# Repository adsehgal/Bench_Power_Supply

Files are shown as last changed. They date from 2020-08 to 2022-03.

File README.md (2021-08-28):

<!-- ![](https://github.com/adsehgal/adsehgal/blob/master/LOGO.png) -->

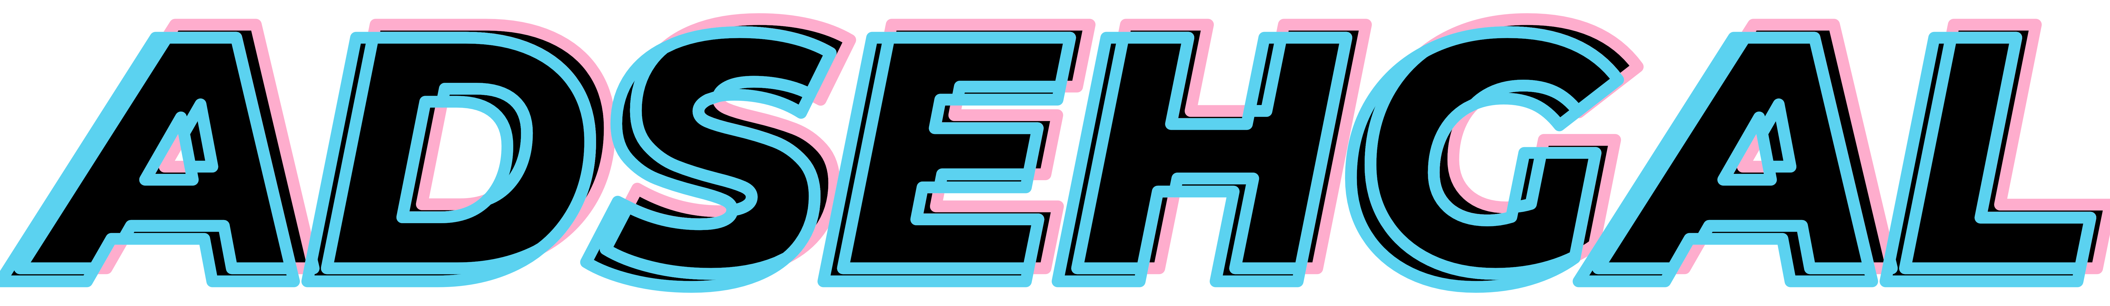
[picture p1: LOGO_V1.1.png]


# _Bench Power Supply PCB_

This repo contains project files for a bench top power supply I designed for my home lab.

## _Requirements:_

- **Small** for crammed work spaces
- **Adjustable** and designed to **store values** on each power cycle
- **2 layer** board - V2.0 bumped to 4 layer
- **Digitally controlled** - no mechanical parts
- Clear **annunciators**
- Uses an external AC-DC converter
- At least a **2A max** load
- Cover most logic levels
- _Possibly have preset buttons_

## Built With:

#### V1.0:

- [KiCad](https://kicad-pcb.org/) - Schematic capture and layout V1.0
- [VS Code | PlatformIO](https://code.visualstudio.com/) - Used to develop firmware V1.0
- [Fusion 360](https://www.autodesk.com/education/edu-software/overview) - Used to design 3-D models for packages

#### V2.0:

- [Altium Designer](https://www.altium.com/) - Schematic capture and layout V2.0
- [STM32CubeIDE](https://www.st.com/en/development-tools/stm32cubeide.html) - Used to develop firmware V2.0

## Notes:

- The PCB uses a 5/5mil DRC constraint
- The top of the PCB acts as the product face plate

## Firmware Changes:

| Change Type | V 1.0 | V2.0 |
| --- | --- | --- |
| MCU Architecture | 8-bit AVR | 32-bit ARM |
| User Input Handling  | Polling | Interrupts |
| Analog Readings | Polling | DMA |
| Serial Communication | None | Added |
| Operating System | None | FREERTOS |
| | | |

## Hardware Changes:

| Change Type | V 1.0 | V2.0 |
| --- | --- | --- |
| MCU Selection | ATMega 328p | STM32F401RB |
| Digi Pot | MCP4023 - Up/Down | MCP4018 - I2C |
| Inductor Seletion | 4.7µH - 7A | 4.7µH - 4A |
| PCB Stackup | 2-layer | 4-layer |
| User Input Buffer | None | Schmitt triggered |
| Analog Buffers | LM358 - Not RRIO  | TLV271 - RRIO |
| MCU VDD | Not always on | Always On |
| OLED Reset | None | Added |
| | | |

## Authors

- **Aditya Sehgal** - _PCB Layout, Firmware, 3-D Modelling_ - [Adsehgal](https://github.com/adsehgal)

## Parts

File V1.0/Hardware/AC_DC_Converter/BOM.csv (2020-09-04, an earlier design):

BOM
Comment | Designator | Footprint | LCSC | Qty
10nF | C1,C8 | Capacitor_SMD:C_0805_2012Metric |  | 2
1µF | C11,C26,C29,C30,C31,C33 | Capacitor_SMD:C_0805_2012Metric |  | 6
2.2nF | C13 | Capacitor_SMD:C_0805_2012Metric |  | 1
22pF | C14,C15,C17 | Capacitor_SMD:C_0805_2012Metric |  | 3
100nF | C2,C3,C6,C9,C10,C19,C20,C21,C22,C23,C24,C25,C27,C28,C35 | Capacitor_SMD:C_0805_2012Metric |  | 15
2.2µF | C34 | Capacitor_SMD:C_0805_2012Metric |  | 1
4.7µF | C4,C5,C16,C18,C32 | Capacitor_SMD:C_0805_2012Metric |  | 5
10uF | C7,C12 | Capacitor_SMD:C_Elec_5x5.4 |  | 2
CL | D1 | LED_SMD:LED_0805_2012Metric |  | 1
OUT | D2 | LED_SMD:LED_0805_2012Metric |  | 1
BAT1000 | D3 | Package_TO_SOT_SMD:TSOT-23 |  | 1
CUS10S30 | D4,D5,D6,D7,D8,D9 | Diode_SMD:D_SOD-323 |  | 6
MF-PSMF020X-2 | F1 | Fuse:Fuse_0805_2012Metric_Castellated |  | 1
MountingHole_Pad | H1,H2,H3,H4 | MountingHole:MountingHole_2.2mm_M2_ISO7380_Pad |  | 4
Conn_01x01 | J2,J3 | Binding_Post:Binding_Post |  | 2
Screw_Terminal_01x02 | J4 | TerminalBlock_Altech:Altech_AK300_1x02_P5.00mm_45-Degree |  | 1
USB_C_Receptacle_USB2.0 | J5 | Connector_USB:USB_C_Receptacle_HRO_TYPE-C-31-M-12 |  | 1
4.7µH | L1 | Inductor_SMD:L_Bourns_SRR1260 |  | 1
FDN335N | Q1,Q2,Q3 | Package_TO_SOT_SMD:SOT-23 |  | 3
330R | R1,R2 | Resistor_SMD:R_0805_2012Metric |  | 2
0.01R | R13 | Resistor_SMD:R_1020_2550Metric |  | 1
390K | R15 | Resistor_SMD:R_0805_2012Metric |  | 1
14K | R16,R19,R23 | Resistor_SMD:R_0805_2012Metric |  | 3
500K | R18 | Resistor_SMD:R_0805_2012Metric |  | 1
1K | R21,R22,R25 | Resistor_SMD:R_0805_2012Metric |  | 3
10K | R3,R6,R8,R9,R10,R12,R17,R20,R24 | Resistor_SMD:R_0805_2012Metric |  | 9
5.1K | R4,R11 | Resistor_SMD:R_0805_2012Metric |  | 2
2.2K | R5,R14 | Resistor_SMD:R_0805_2012Metric |  | 2
37.4K | R7 | Resistor_SMD:R_0805_2012Metric |  | 1
UP | SW1 | Button_Switch_SMD:SW_SPST_TL3342 |  | 1
DW | SW2 | Button_Switch_SMD:SW_SPST_TL3342 |  | 1
V_I_SEL | SW3 | Button_Switch_SMD:SW_SPST_TL3342 |  | 1
O_EN | SW4 | Button_Switch_SMD:SW_SPST_TL3342 |  | 1
TestPoint | TP1,TP2,TP3,TP4,TP5,TP6 | TestPoint:TestPoint_Pad_D1.0mm |  | 6
MIC5205-5.0YM5 | U1 | Package_TO_SOT_SMD:SOT-23-5 |  | 1
SSD1306_0.96in | U10 | Custom_Displays:SSD1306_0.96in |  | 1
ATmega328PB-AU | U2 | Package_QFP:TQFP-32_7x7mm_P0.8mm |  | 1
TPS54531DDAR | U3 | Package_SO:SOIC-8-1EP_3.9x4.9mm_P1.27mm_EP2.514x3.2mm |  | 1
LM358 | U4,U11 | Package_SO:MSOP-8_3x3mm_P0.65mm |  | 2
INA138 | U5 | Package_TO_SOT_SMD:SOT-23-5 |  | 1
MCP4023-103ECH | U6 | Package_TO_SOT_SMD:SOT-23-6 |  | 1
CH340E | U7 | Package_SO:MSOP-10_3x3mm_P0.5mm |  | 1
MIC5205-3.3YM5 | U8 | Package_TO_SOT_SMD:SOT-23-5 |  | 1
PCA9306 | U9 | Package_SO:VSSOP-8_2.3x2mm_P0.5mm |  | 1
16MHz | Y1 | Crystal:Crystal_SMD_SeikoEpson_TSX3225-4Pin_3.2x2.5mm |  | 1

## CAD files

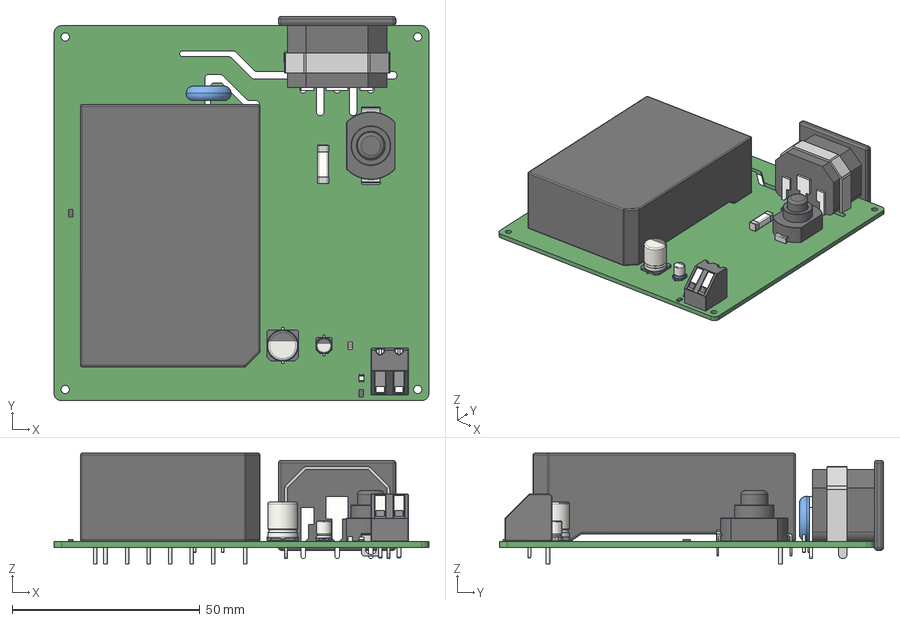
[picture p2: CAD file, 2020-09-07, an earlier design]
V1.0/Hardware/AC_DC_Converter/AC_PCB.stp
100.0 x 102.5 x 29.5 mm

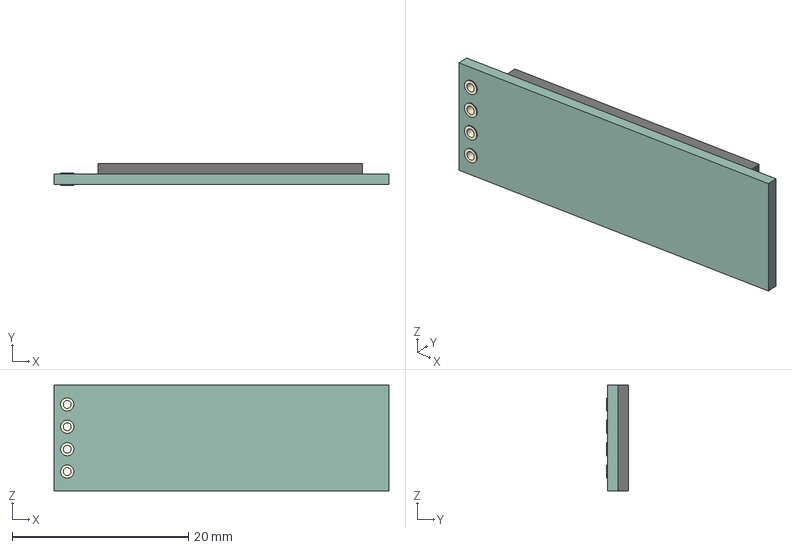
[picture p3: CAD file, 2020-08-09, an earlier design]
V2.0/Hardware/3-D models/0.91_ OLED.step
38.0 x 2.50 x 12.0 mm

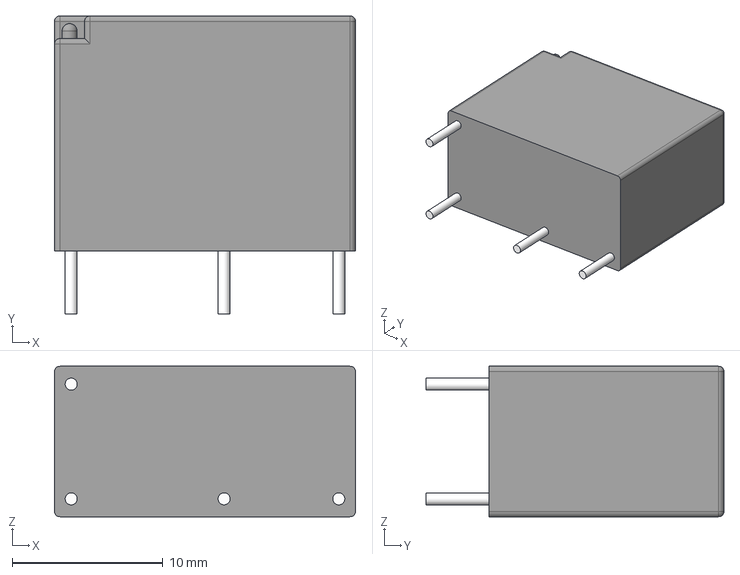
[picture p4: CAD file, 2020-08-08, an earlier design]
V2.0/Hardware/3-D models/Relay_ALQ305.step
20.0 x 19.8 x 10.0 mm

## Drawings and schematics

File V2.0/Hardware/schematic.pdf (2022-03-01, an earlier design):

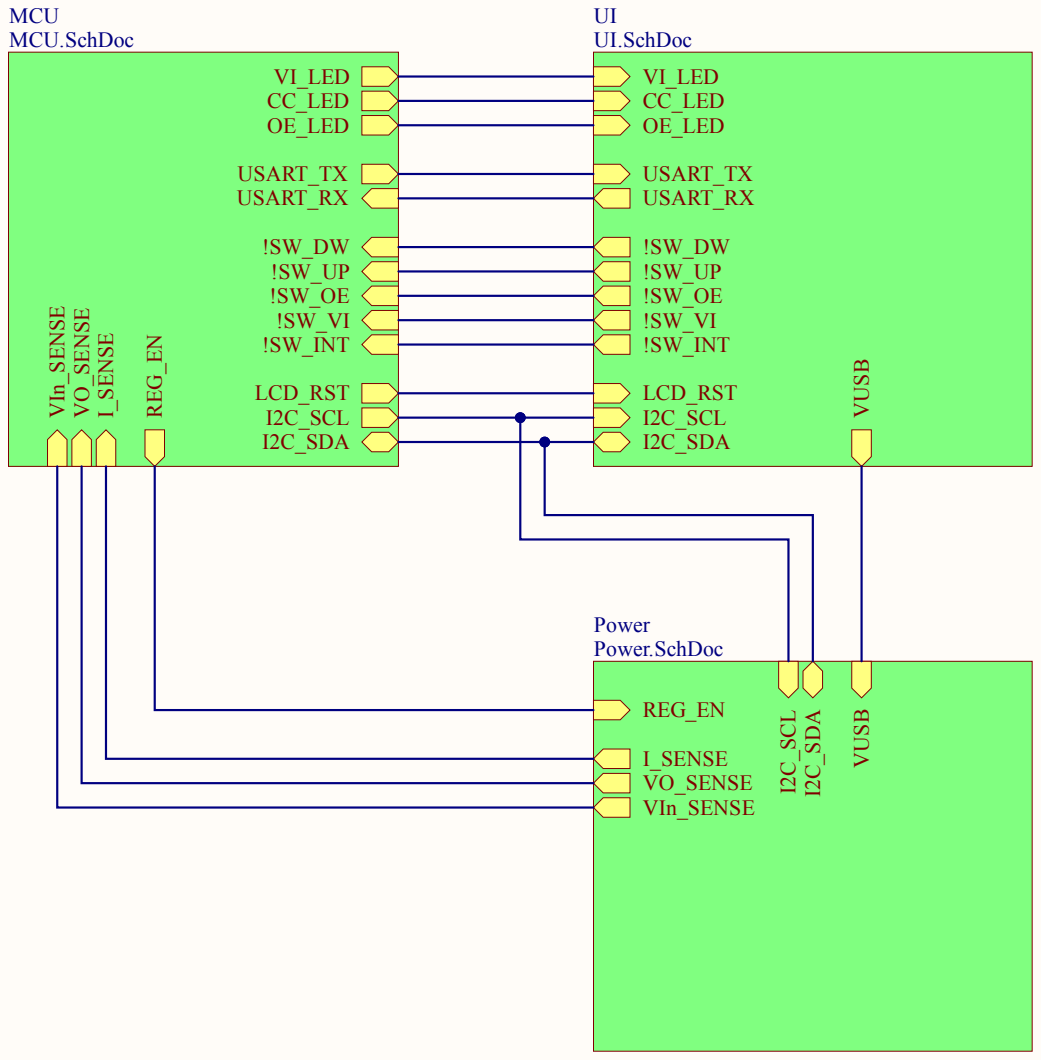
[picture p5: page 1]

I2C_SDA

Power Power.SchDoc

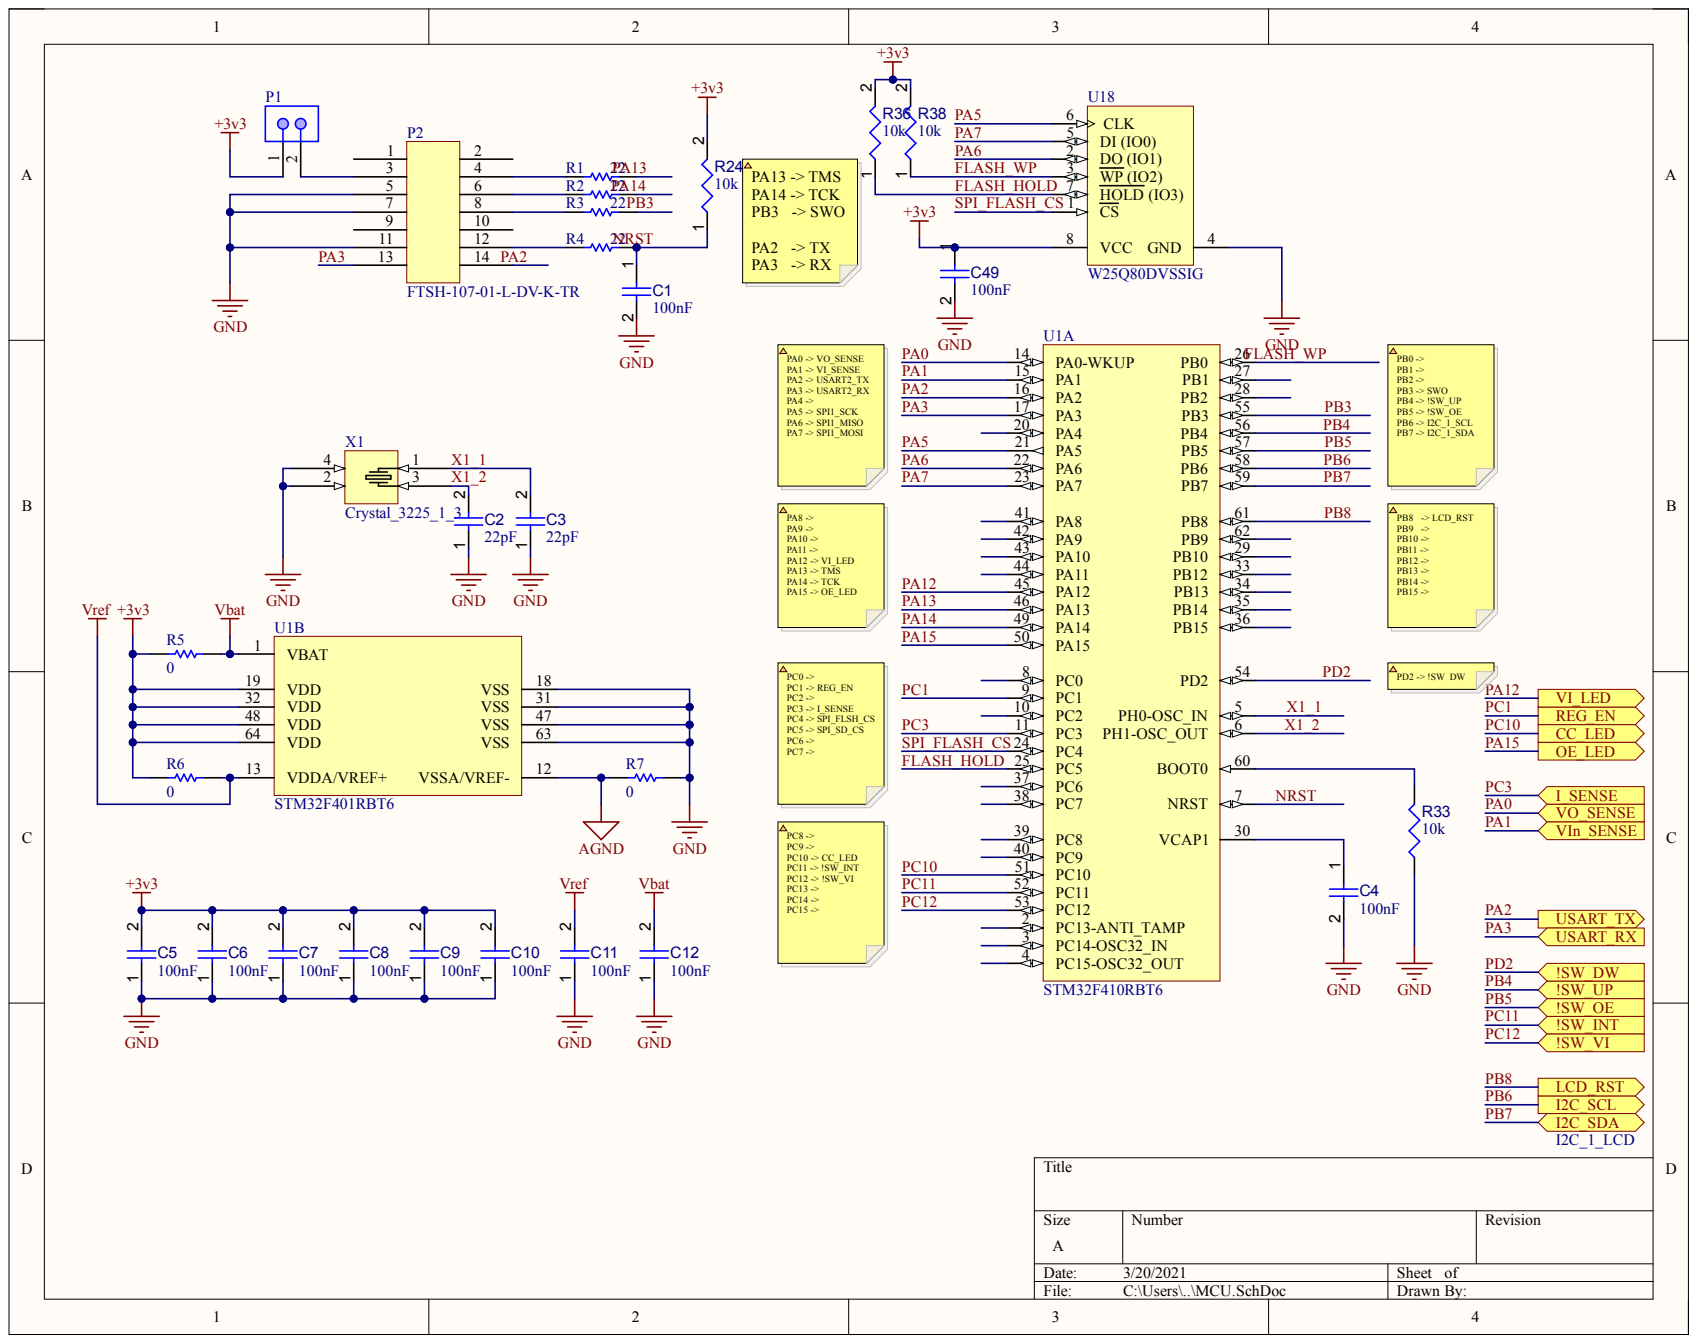
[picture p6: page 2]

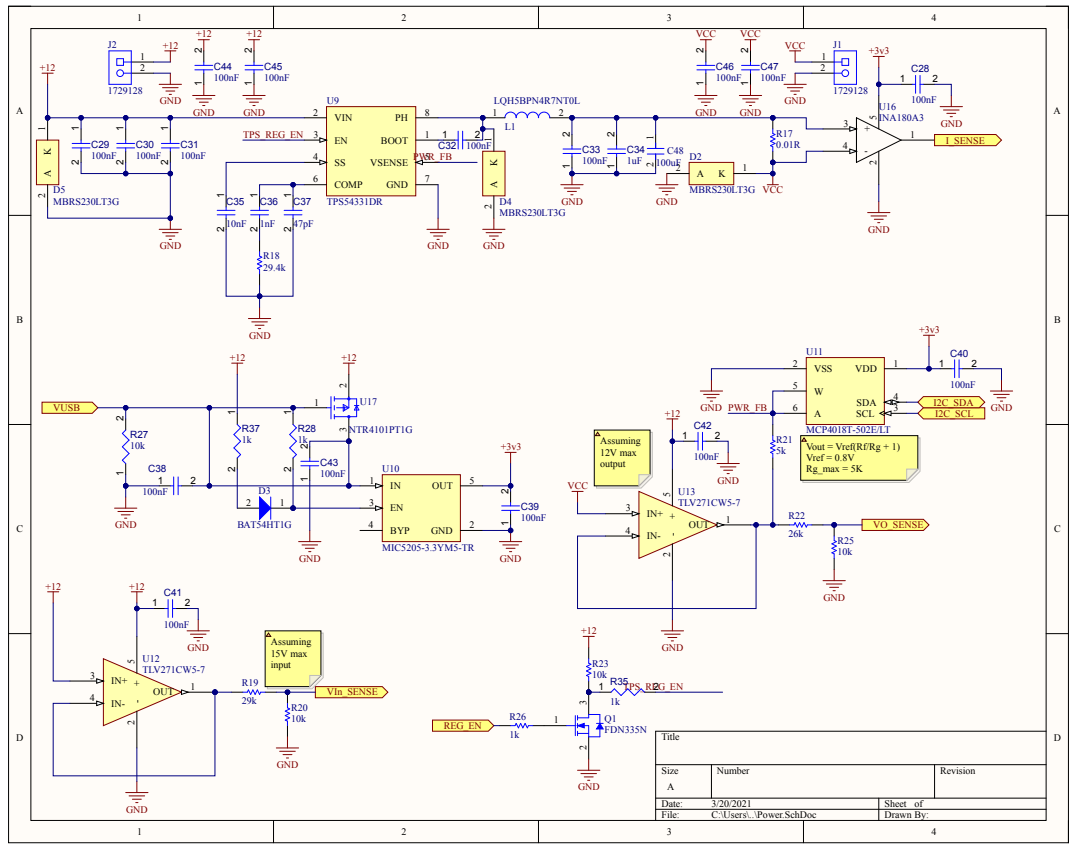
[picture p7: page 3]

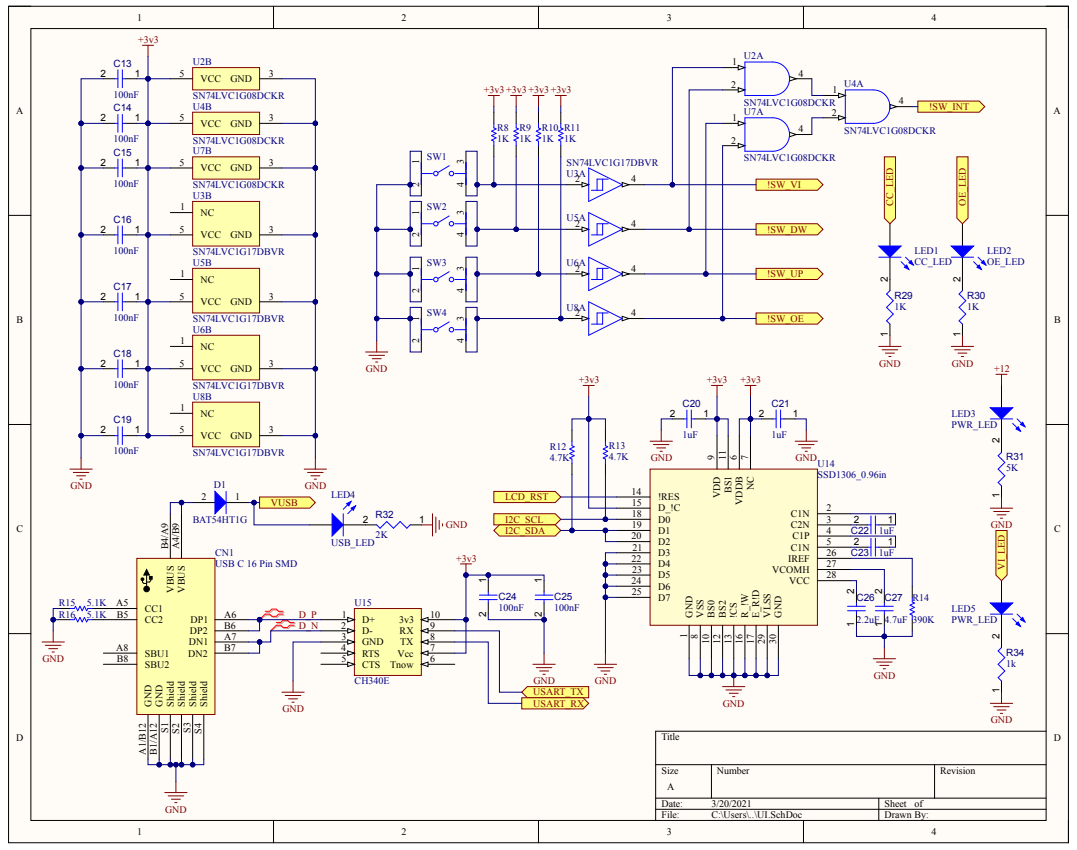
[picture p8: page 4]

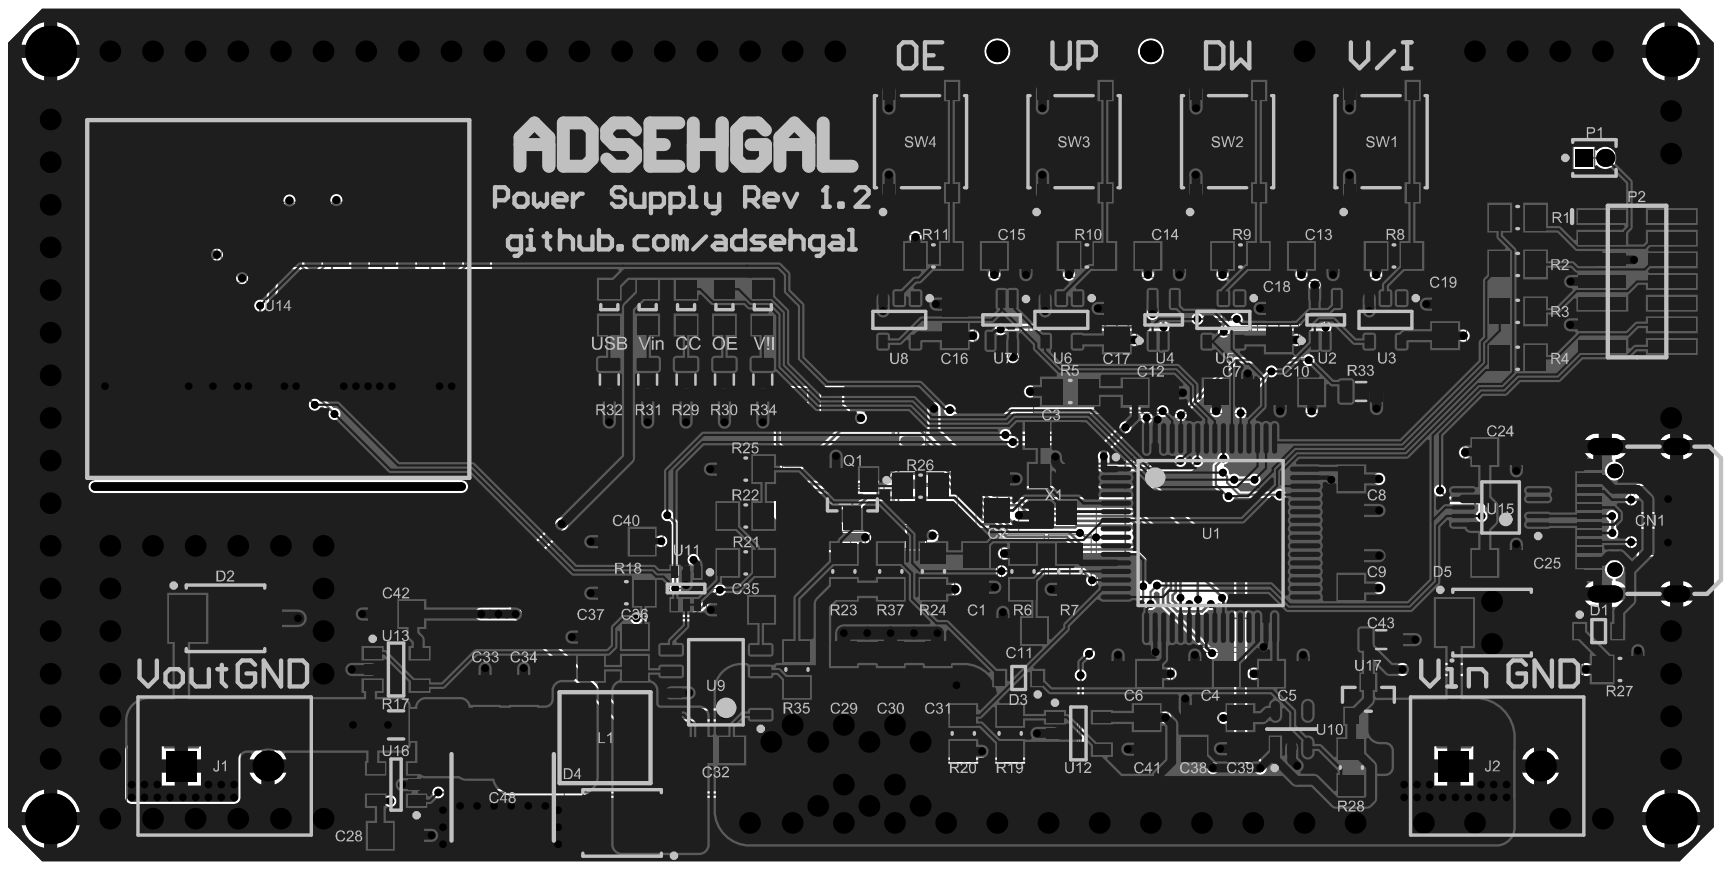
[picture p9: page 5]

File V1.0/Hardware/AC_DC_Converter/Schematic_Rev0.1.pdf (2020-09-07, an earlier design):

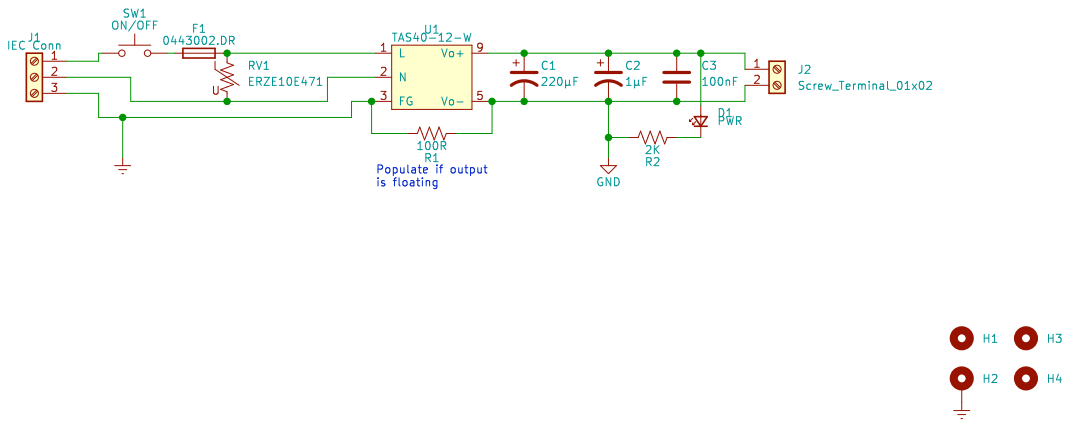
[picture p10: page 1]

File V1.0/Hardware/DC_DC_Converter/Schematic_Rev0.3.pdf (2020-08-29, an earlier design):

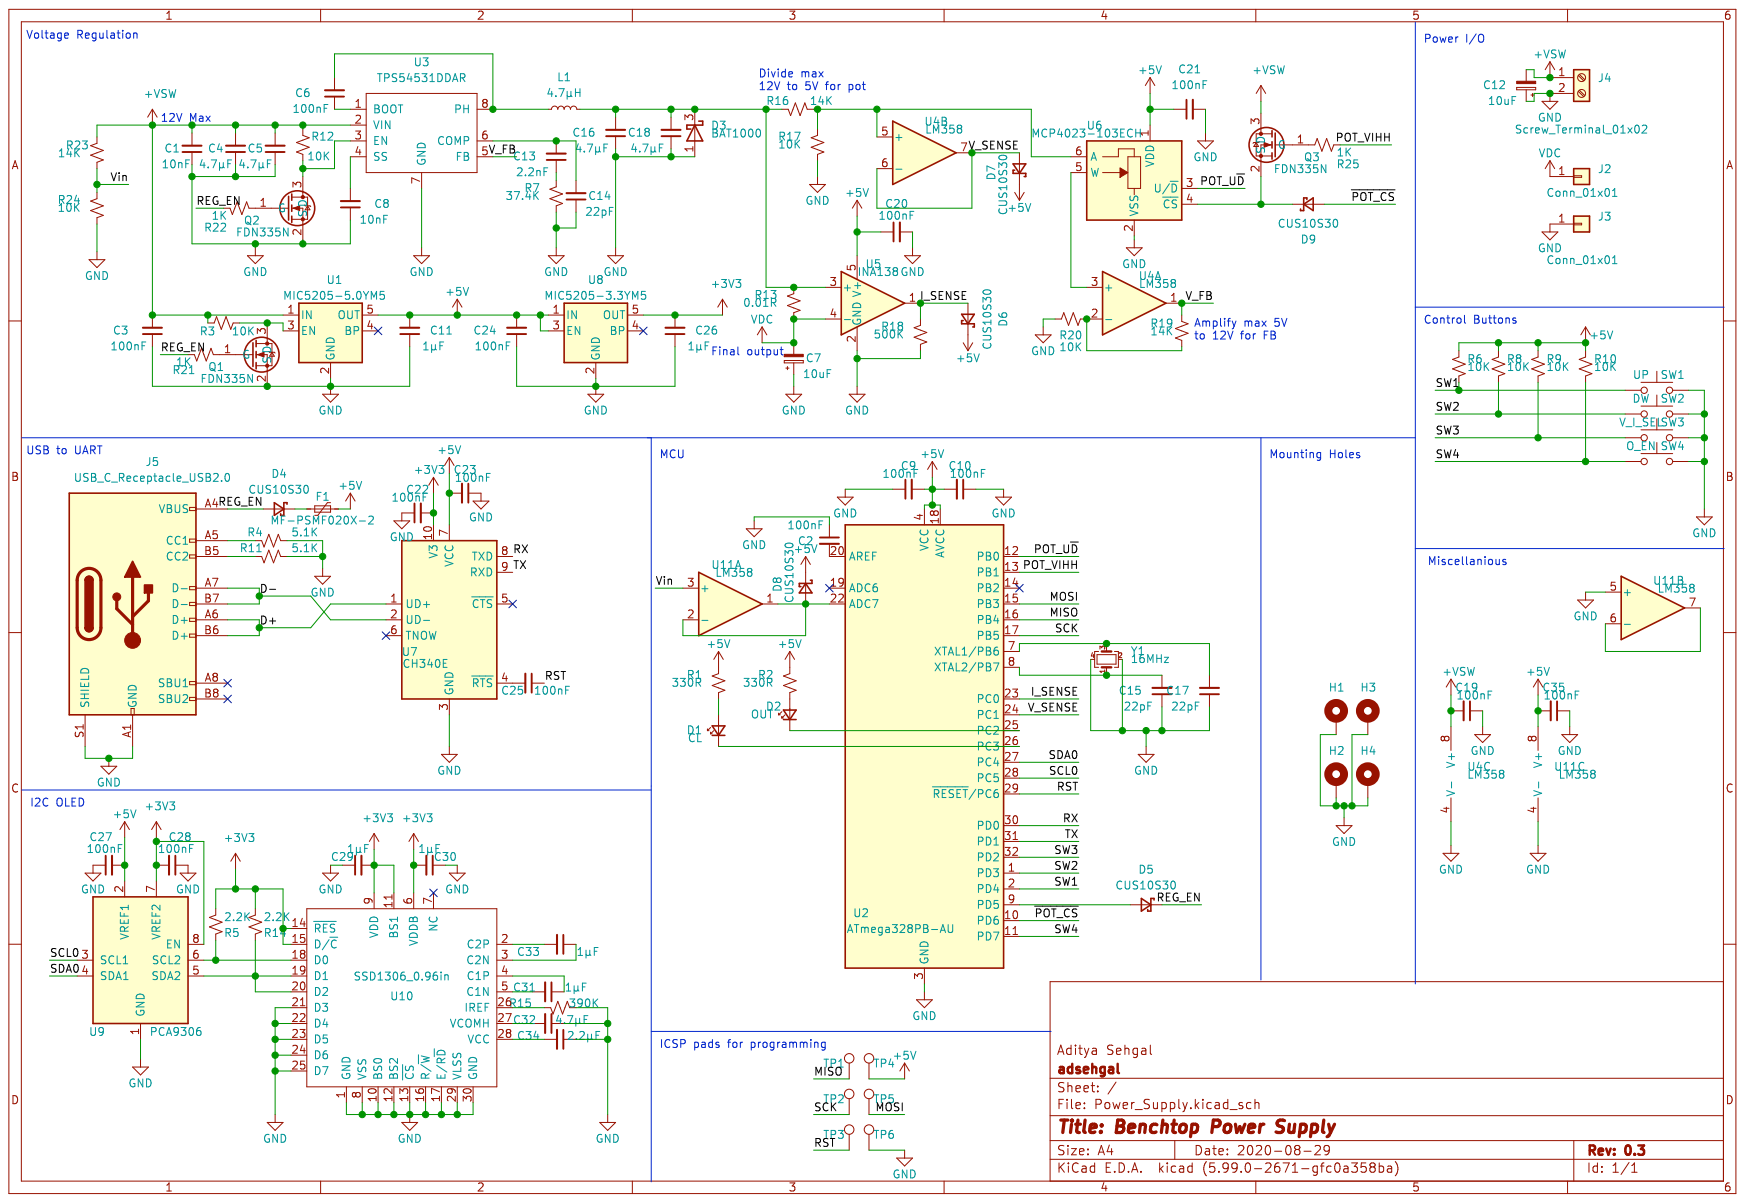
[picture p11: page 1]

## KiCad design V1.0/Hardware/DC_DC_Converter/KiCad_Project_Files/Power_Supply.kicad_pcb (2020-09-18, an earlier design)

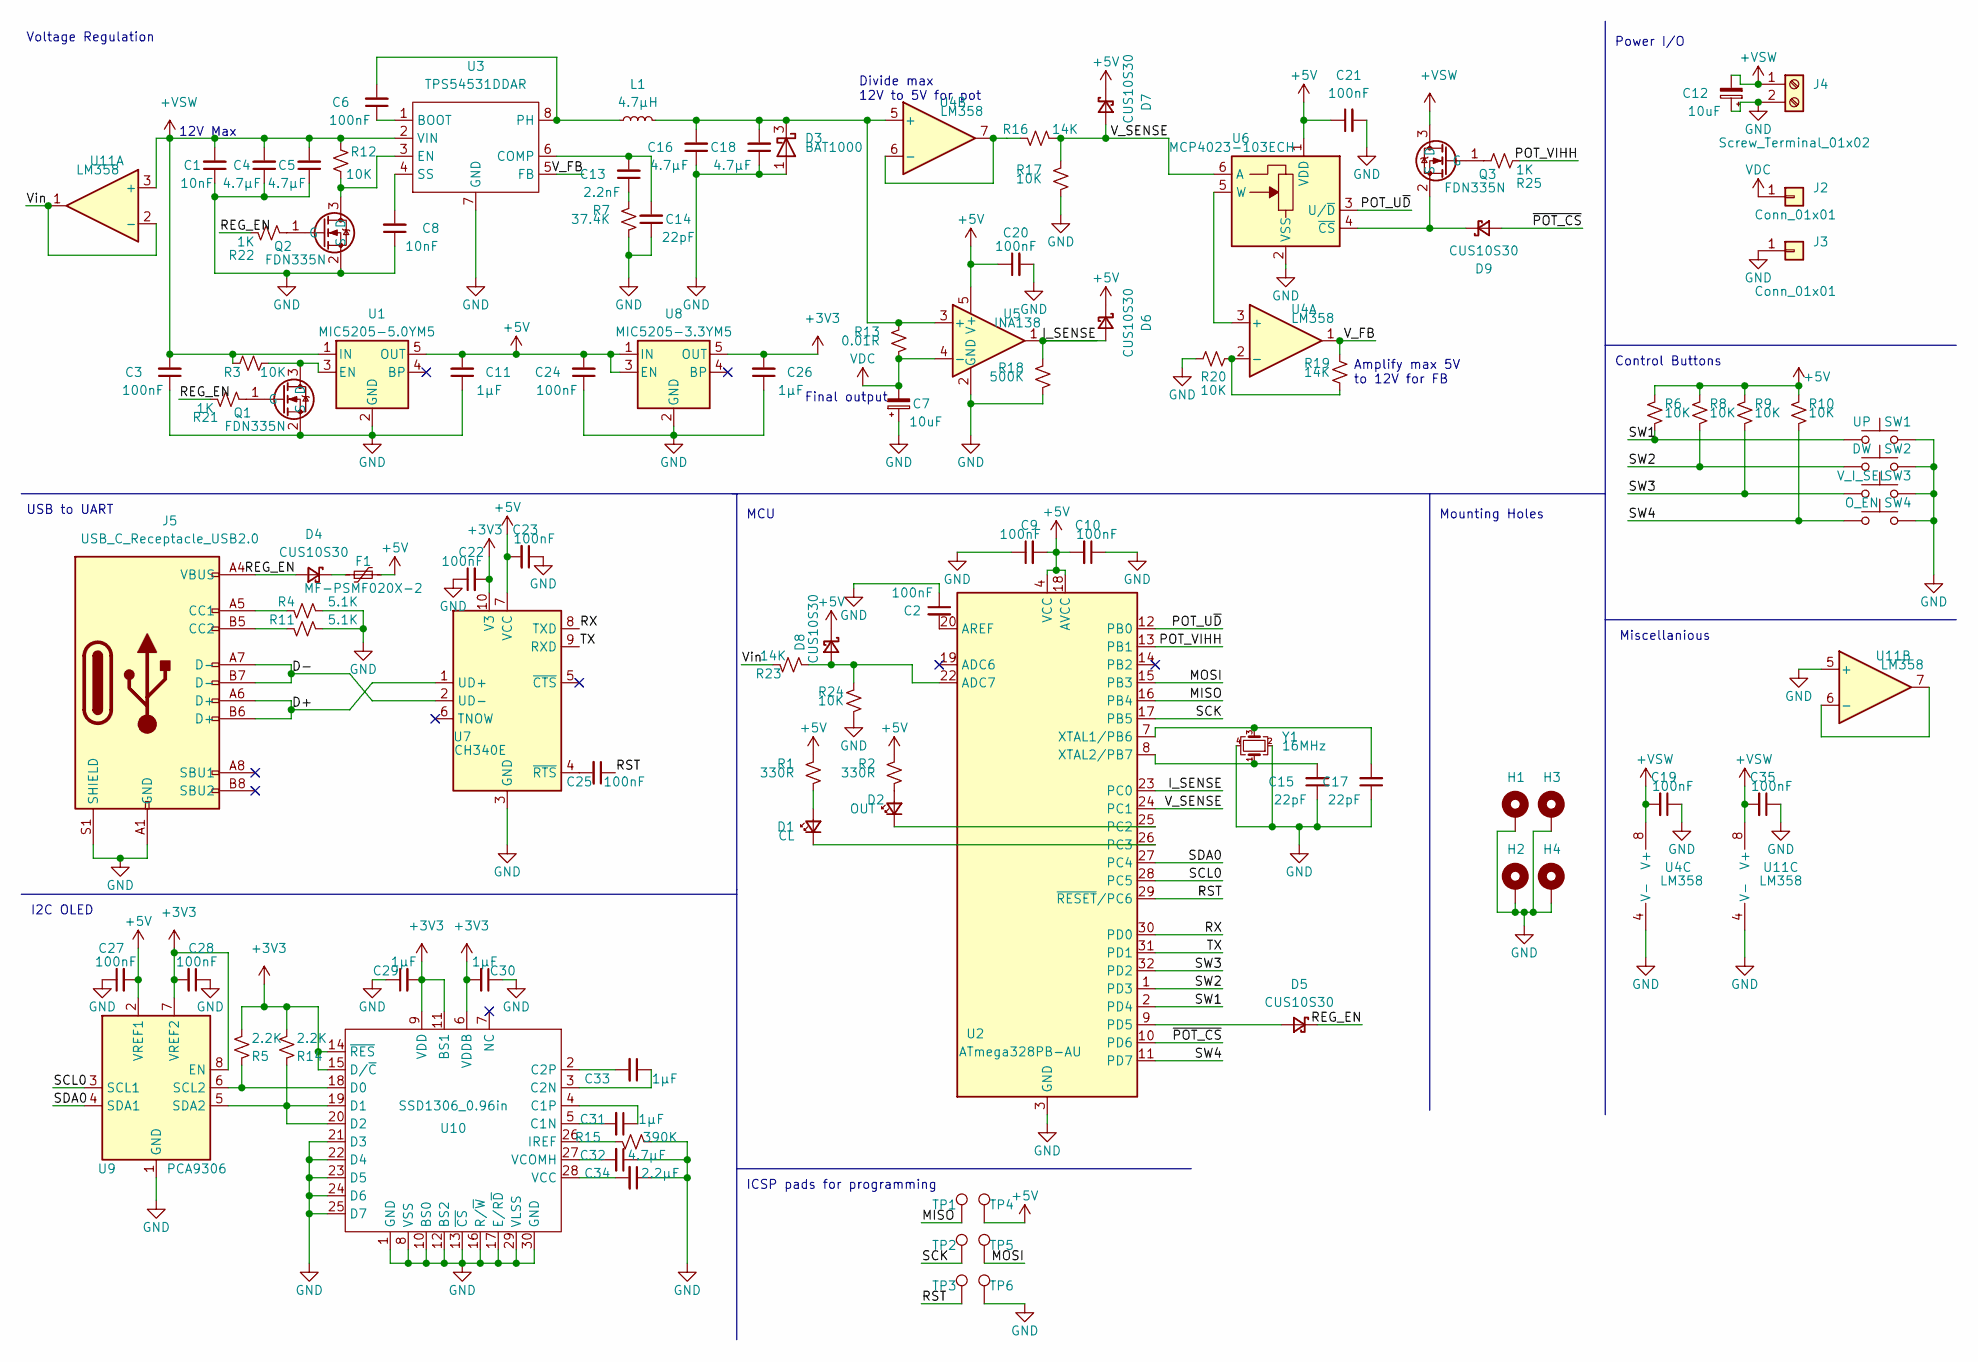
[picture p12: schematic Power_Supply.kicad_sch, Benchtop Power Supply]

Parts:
C1, C8: 10nF; C_0805_2012Metric
C2, C3, C6, C9, C10, C19, C20, C21, C22, C23, C24, C25, C27, C28, C35: 100nF; C_0805_2012Metric
C4, C5, C16, C18, C32: 4.7µF; C_0805_2012Metric
C7, C12: 10uF; C_Elec_5x5.4
C11, C26, C29, C30, C31, C33: 1µF; C_0805_2012Metric
C13: 2.2nF; C_0805_2012Metric
C14, C15, C17: 22pF; C_0805_2012Metric
C34: 2.2µF; C_0805_2012Metric
D1: CL; LED_0805_2012Metric
D2: OUT; LED_0805_2012Metric
D3: BAT1000; TSOT-23
D4, D5, D6, D7, D8, D9: CUS10S30; D_SOD-323
F1: MF-PSMF020X-2; Fuse_0805_2012Metric_Castellated
H1, H2, H3, H4: MountingHole_Pad; MountingHole_2.2mm_M2_ISO7380_Pad
J2, J3: Conn_01x01; Binding_Post
J4: Screw_Terminal_01x02; Altech_AK300_1x02_P5.00mm_45-Degree
J5: USB_C_Receptacle_USB2.0; USB_C_Receptacle_HRO_TYPE-C-31-M-12
L1: 4.7µH; L_Bourns_SRR1260
Q1, Q2, Q3: FDN335N; SOT-23
R1, R2: 330R; R_0805_2012Metric
R3, R6, R8, R9, R10, R12, R17, R20, R24: 10K; R_0805_2012Metric
R4, R11: 5.1K; R_0805_2012Metric
R5, R14: 2.2K; R_0805_2012Metric
R7: 37.4K; R_0805_2012Metric
R13: 0.01R; R_1020_2550Metric
R15: 390K; R_0805_2012Metric
R16, R19, R23: 14K; R_0805_2012Metric
R18: 500K; R_0805_2012Metric
R21, R22, R25: 1K; R_0805_2012Metric
SW1: UP; SW_SPST_TL3342
SW2: DW; SW_SPST_TL3342
SW3: V_I_SEL; SW_SPST_TL3342
SW4: O_EN; SW_SPST_TL3342
TP1, TP2, TP3, TP4, TP5, TP6: TestPoint; TestPoint_Pad_D1.0mm
U1: MIC5205-5.0YM5; SOT-23-5
U2: ATmega328PB-AU; TQFP-32_7x7mm_P0.8mm
U3: TPS54531DDAR; SOIC-8-1EP_3.9x4.9mm_P1.27mm_EP2.514x3.2mm
U4, U11: LM358; MSOP-8_3x3mm_P0.65mm
U5: INA138; SOT-23-5
U6: MCP4023-103ECH; SOT-23-6
U7: CH340E; MSOP-10_3x3mm_P0.5mm
U8: MIC5205-3.3YM5; SOT-23-5
U9: PCA9306; VSSOP-8_2.3x2mm_P0.5mm
U10: SSD1306_0.96in
Y1: 16MHz; Crystal_SMD_SeikoEpson_TSX3225-4Pin_3.2x2.5mm

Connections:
+3V3: C22.2, C26.2, C28.2, C29.2, C30.2, R5.1, R14.1, U7.10 (V3), U8.5 (OUT), U9.7 (VREF2), U9.8 (EN), U10.6 (VDDB), U10.9 (VDD), U10.11 (BS1), U10.14 (~RES), U10.15 (D/~C)
+5V: C9.2, C10.2, C11.2, C20.1, C21.1, C23.2, C24.2, C27.2, D6.1 (K), D7.1 (K), D8.1 (K), F1.2, R1.2, R2.2, R6.1, R8.1, R9.1, R10.1, TP4.1, U1.5 (OUT), U2.4 (VCC), U2.6 (VCC), U2.18 (AVCC), U5.5 (V+), U6.1 (VDD), U7.7 (VCC), U8.1 (IN), U8.3 (EN), U9.2 (VREF1)
+VSW: C1.2, C3.2, C4.2, C5.2, C12.2, C19.2, C35.2, J4.1, Q3.3 (D), R3.2, R12.2, U1.1 (IN), U3.2 (VIN), U4.8 (V+), U11.3 (+), U11.8 (V+)
/D+: J5.A6 (D+), J5.B6 (D+), U7.1 (UD+)
/D-: J5.A7 (D-), J5.B7 (D-), U7.2 (UD-)
/I_SENSE: D6.2 (A), R18.2, U2.23 (PC0), U5.1
/MISO: TP1.1, U2.16 (PB4)
/MOSI: TP5.1, U2.15 (PB3)
/POT_U~D: U2.12 (PB0), U6.3 (U/~D)
/POT_VIHH: R25.2, U2.13 (PB1)
/REG_EN: D4.2 (A), D5.1 (K), J5.A4 (VBUS), J5.A9 (VBUS), J5.B4 (VBUS), J5.B9 (VBUS), R21.2, R22.2
/RST: C25.1, TP3.1, U2.29 (~RESET~/PC6)
/RX: U2.30 (PD0), U7.8 (TXD)
/SCK: TP2.1, U2.17 (PB5)
/SCL0: U2.28 (PC5), U9.3 (SCL1)
/SDA0: U2.27 (PC4), U9.4 (SDA1)
/SW1: R6.2, SW1.1, U2.2 (PD4)
/SW2: R8.2, SW2.1, U2.1 (PD3)
/SW3: R9.2, SW3.1, U2.32 (PD2)
/SW4: R10.2, SW4.1, U2.11 (PD7)
/TX: U2.31 (PD1), U7.9 (RXD)
/V_FB: R19.1, U3.5 (FB), U4.1
/V_SENSE: D7.2 (A), R16.1, R17.2, U2.24 (PC1), U6.6 (A)
/Vin: R23.1, U11.1, U11.2 (-)
/~POT_CS: D9.2 (A), U2.10 (PD6)
GND: C1.1, C2.1, C3.1, C4.1, C5.1, C7.1, C8.1, C9.1, C10.1, C11.1, C12.1, C14.1, C15.1, C16.1, C17.1, C18.1, C19.1, C20.2, C21.2, C22.1, C23.1, C24.1, C26.1, C27.1, C28.1, C29.1, C30.1, C32.1, C34.1, C35.1, D3.1, H1.1, H2.1, H3.1, H4.1, J3.1, J4.2, J5.A1 (GND), J5.A12 (GND), J5.B1 (GND), J5.B12 (GND), J5.S1 (SHIELD), Q1.2 (S), Q2.2 (S), R4.1, R7.1, R11.1, R15.1, R17.1, R18.1, R20.2, R24.1, SW1.2, SW2.2, SW3.2, SW4.2, TP6.1, U1.2 (GND), U2.3 (GND), U2.5 (GND), U2.21 (GND), U3.7 (GND), U3.9 (GND), U4.4 (V-), U5.2 (GND), U6.2 (VSS), U7.3 (GND), U8.2 (GND), U9.1 (GND), U10.1 (GND), U10.8 (VSS), U10.10 (BS0), U10.12 (BS2), U10.13 (~CS), U10.16 (R/~W), U10.17 (E/R~D), U10.21 (D3), U10.22 (D4), U10.23 (D5), U10.24 (D6), U10.25 (D7), U10.29 (VLSS), U10.30 (GND), U11.4 (V-), U11.5 (+), Y1.2, Y1.4
unnamed: C2.2, U2.20 (AREF)
unnamed: C6.1, U3.1 (BOOT)
unnamed: C6.2, L1.1, U3.8 (PH)
unnamed: C8.2, U3.4 (SS)
unnamed: C13.1, R7.2
unnamed: C13.2, C14.2, U3.6 (COMP)
unnamed: C15.2, U2.8 (XTAL2/PB7), Y1.1
unnamed: C16.2, C18.2, D3.3, L1.2, R13.2, U4.5 (+), U5.3 (+)
unnamed: C17.2, U2.7 (XTAL1/PB6), Y1.3
unnamed: C25.2, U7.4 (~RTS)
unnamed: C31.1, U10.4 (C1P)
unnamed: C31.2, U10.5 (C1N)
unnamed: C32.2, U10.27 (VCOMH)
unnamed: C33.1, U10.3 (C2N)
unnamed: C33.2, U10.2 (C2P)
unnamed: C34.2, U10.28 (VCC)
unnamed: D1.1 (K), U2.26 (PC3)
unnamed: D1.2 (A), R1.1
unnamed: D2.1 (K), U2.25 (PC2)
unnamed: D2.2 (A), R2.1
unnamed: D4.1 (K), F1.1
unnamed: D5.2 (A), U2.9 (PD5)
unnamed: D8.2 (A), R23.2, R24.2, U2.22 (ADC7)
unnamed: D9.1 (K), Q3.2 (S), U6.4 (~CS)
unnamed: J5.A5 (CC1), R4.2
unnamed: J5.B5 (CC2), R11.2
unnamed: Q1.1 (G), R21.1
unnamed: Q1.3 (D), R3.1, U1.3 (EN)
unnamed: Q2.1 (G), R22.1
unnamed: Q2.3 (D), R12.1, U3.3 (EN)
unnamed: Q3.1 (G), R25.1
unnamed: R5.2, U9.6 (SCL2), U10.18 (D0)
unnamed: R14.2, U9.5 (SDA2), U10.19 (D1), U10.20 (D2)
unnamed: R15.2, U10.26 (IREF)
unnamed: R16.2, U4.6 (-), U4.7
unnamed: R19.2, R20.1, U4.2 (-)
unnamed: U4.3 (+), U6.5 (W)
unnamed: U11.6 (-), U11.7
VDC: C7.2, J2.1, R13.1, U5.4 (-)

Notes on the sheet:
Voltage Regulation
USB to UART
I2C OLED
12V Max
MCU
ICSP pads for programming
Final output
Divide max 12V to 5V for pot
Amplify max 5V to 12V for FB
Mounting Holes
Power I/O
Control Buttons
Miscellanious

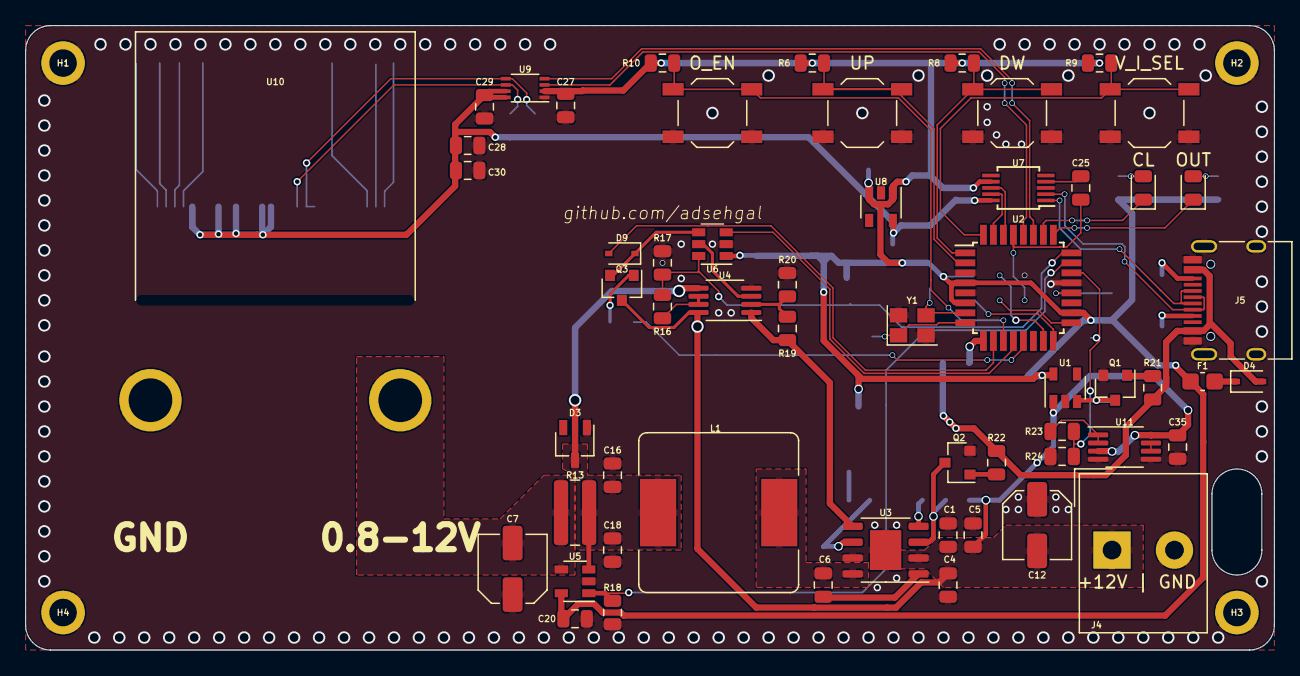
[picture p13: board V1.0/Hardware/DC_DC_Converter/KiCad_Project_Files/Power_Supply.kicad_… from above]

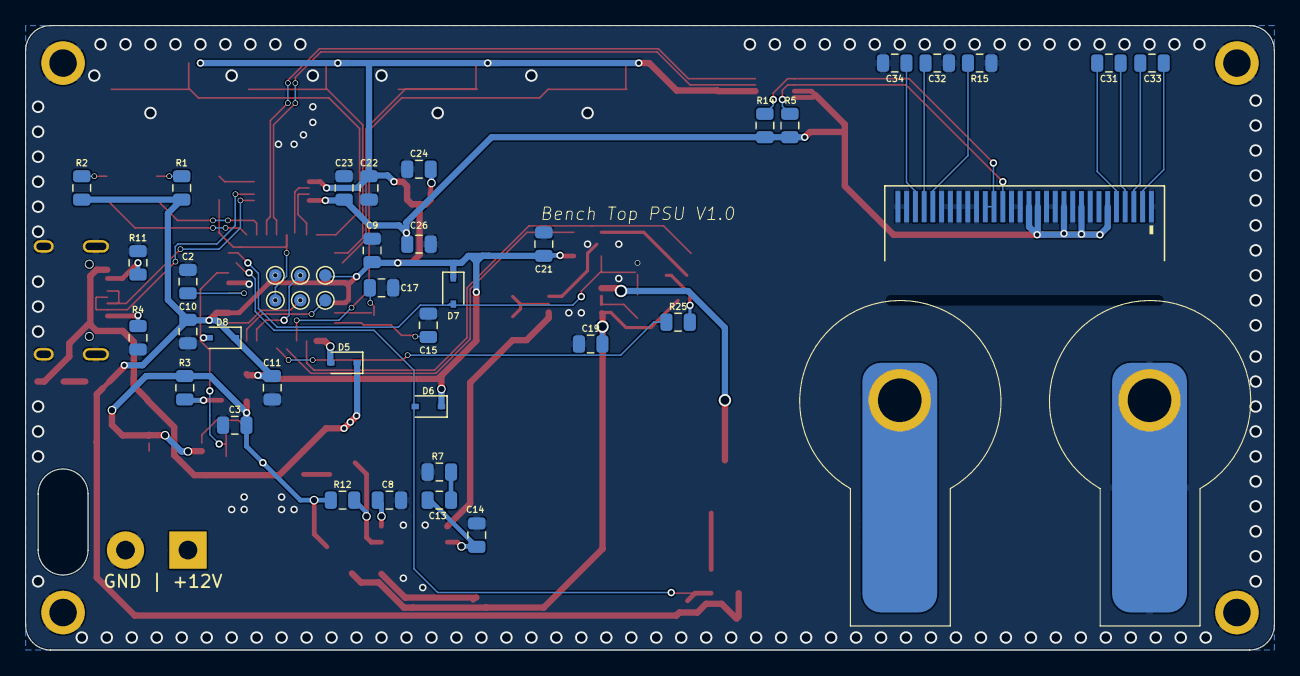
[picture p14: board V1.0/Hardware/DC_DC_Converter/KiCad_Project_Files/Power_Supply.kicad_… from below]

Board: 2 copper layers, 100.0 x 50.0 mm, 104 parts (41 on the bottom side), 65 nets.

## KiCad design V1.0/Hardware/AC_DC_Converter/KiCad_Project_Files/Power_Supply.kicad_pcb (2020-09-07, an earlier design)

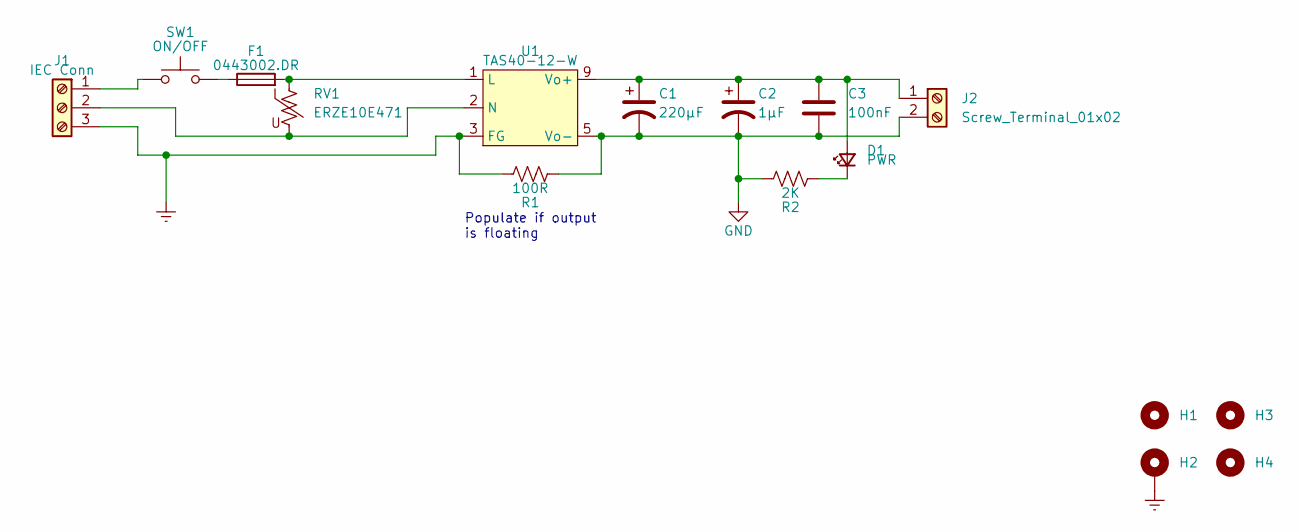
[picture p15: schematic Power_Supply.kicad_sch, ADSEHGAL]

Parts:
C1: 220µF; CP_Elec_8x10.5
C2: 1µF; CP_Elec_4x5.4
C3: 100nF; C_0805_2012Metric
D1: PWR; LED_0805_2012Metric_Castellated
F1: 0443002.DR; LittleFuse-0443002
H1, H3, H4: MountingHole; MountingHole_2.2mm_M2_DIN965_Pad
H2: Earth; MountingHole_2.2mm_M2_DIN965_Pad
J1: IEC Conn; ACT3KD-03BT3B018
J2: Screw_Terminal_01x02; Altech_AK300_1x02_P5.00mm_45-Degree
R1: 100R; R_0805_2012Metric
R2: 2K; R_0805_2012Metric
RV1: ERZE10E471; RV_Disc_D12mm_W3.9mm_P7.5mm
SW1: ON/OFF; BPT
U1: TAS40-12-W

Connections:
Earth: H2.1, J1.3, R1.2, U1.3 (FG)
GND: C1.2, C2.2, C3.2, J2.2, R1.1, R2.2, U1.5 (Vo-)
unnamed: C1.1, C2.1, C3.1, D1.2 (A), J2.1, U1.9 (Vo+)
unnamed: D1.1 (K), R2.1
unnamed: F1.1, SW1.2
unnamed: F1.2, RV1.1, U1.1 (L)
unnamed: J1.1, SW1.1
unnamed: J1.2, RV1.2, U1.2 (N)

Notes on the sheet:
Populate if output is floating

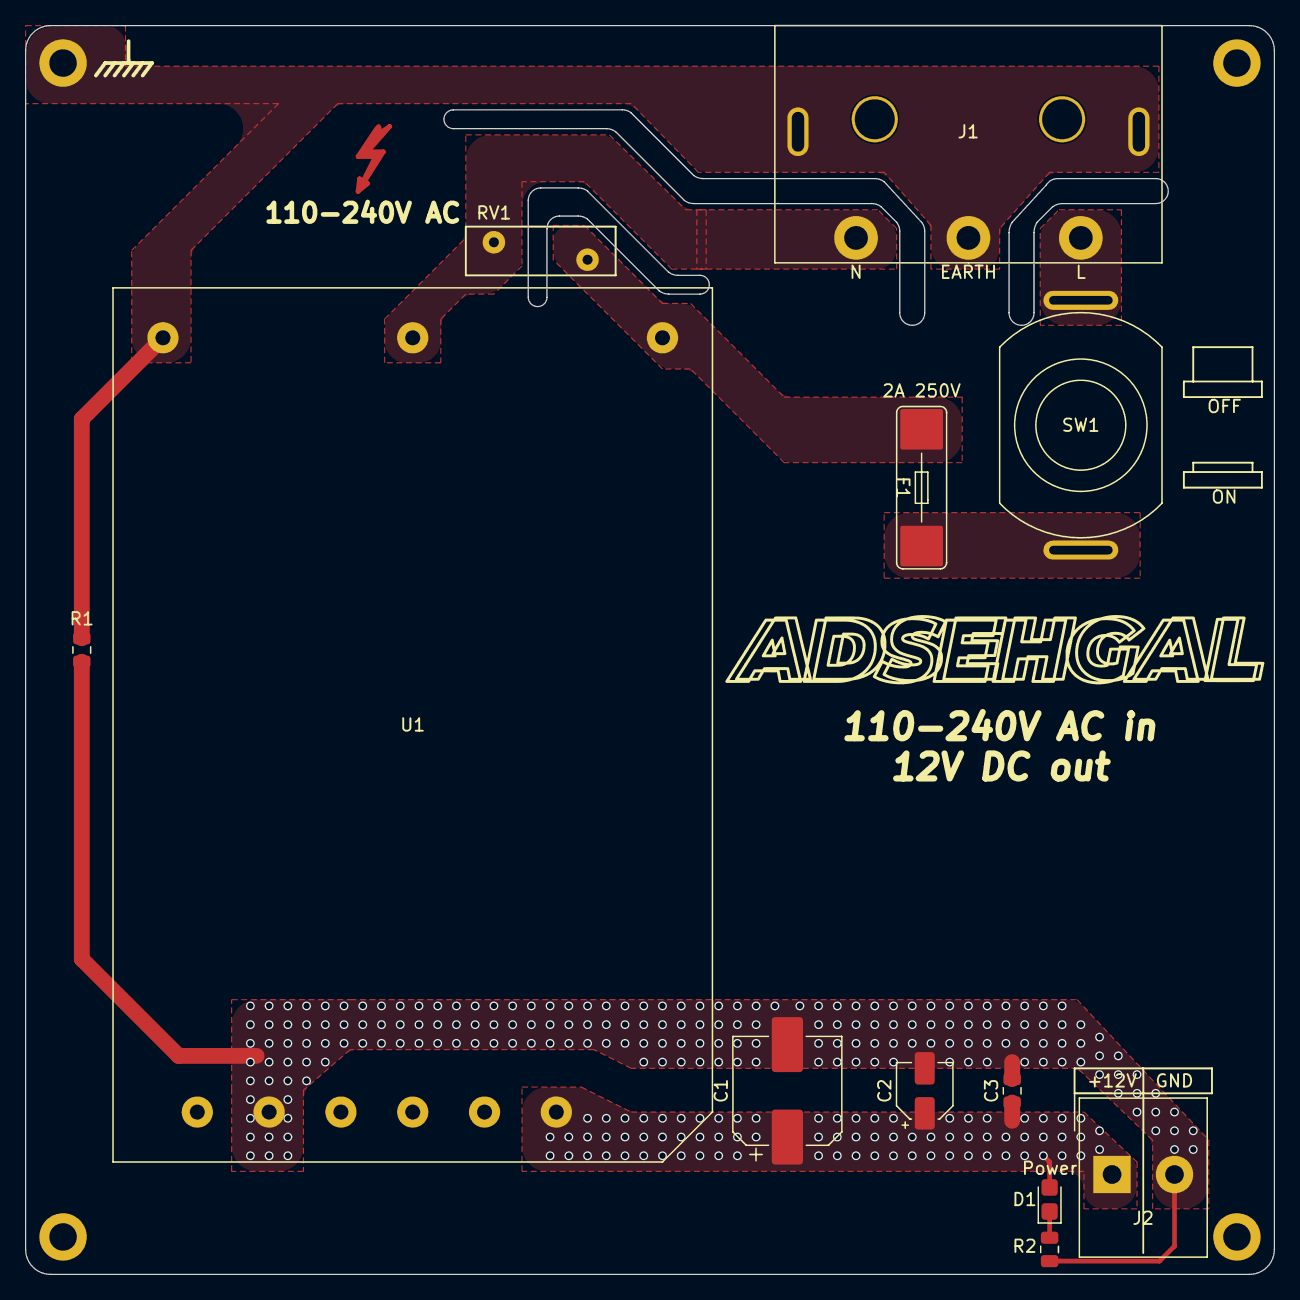
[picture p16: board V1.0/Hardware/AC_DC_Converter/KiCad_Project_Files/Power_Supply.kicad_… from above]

Board: 2 copper layers, 100.0 x 100.0 mm, 16 parts (0 on the bottom side), 8 nets.

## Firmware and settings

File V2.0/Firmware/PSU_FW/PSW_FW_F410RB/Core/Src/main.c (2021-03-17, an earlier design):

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
/* Includes ------------------------------------------------------------------*/
#include "main.h"

/* USER CODE BEGIN Includes */
#include <stdio.h>
#include <string.h>
#include <stdlib.h>

#include "debug.h"

#include "analog.h"

#include "buttons.h"

#include "gfx.h"
#include "ssd1306.h"

#include "leds.h"

#include "mcp4018.h"

/* USER CODE END Includes */

/* USER CODE BEGIN PD */
#define INFO_TEXT_SIZE Font_7x10
#define ERROR_TEXT_SIZE Font_11x18
#define REFRESH_INTERVAL 2500	// 2500 / (84Ε6 / 8400) = 0.25s
/* USER CODE END PD */

ADC_HandleTypeDef hadc1;

I2C_HandleTypeDef hi2c1;

TIM_HandleTypeDef htim11;

UART_HandleTypeDef huart2;

/* USER CODE BEGIN PV */
struct Stats psuStats;
uint8_t swIntFlag = RESET;
uint32_t timerVal = 0;
uint8_t timerFlag = RESET;
double gVin = 0;
/* USER CODE END PV */

void SystemClock_Config(void);
static void MX_GPIO_Init(void);
static void MX_ADC1_Init(void);
static void MX_I2C1_Init(void);
static void MX_TIM11_Init(void);
static void MX_USART2_UART_Init(void);
/**
  * @brief  The application entry point.
  * @retval int
  */
int main(void)
{
  /* USER CODE BEGIN 1 */
#warning CHECK WHAT CRYSTAL IS BEING USED - 16MHz or 8MHz
  /* USER CODE END 1 */

  /* MCU Configuration--------------------------------------------------------*/

  /* Reset of all peripherals, Initializes the Flash interface and the Systick. */
  HAL_Init();

  /* Configure the system clock */
  SystemClock_Config();

  /* Initialize all configured peripherals */
  MX_GPIO_Init();
  MX_ADC1_Init();
  MX_I2C1_Init();
  MX_TIM11_Init();
  MX_USART2_UART_Init();
  /* USER CODE BEGIN 2 */

	//check for i2c devices
	uint8_t i2cScanRet = i2cScan();
	if (!i2cScanRet)
	{
		errorLEDs(i2cScanRet);
	}
	printMsg("no I2C errors\n\n");

	//initialize entire system
	initPSU();
  /* USER CODE END 2 */

  /* Infinite loop */
  /* USER CODE BEGIN WHILE */
	while (1)
	{

		//get all info from ADCs
		double Vin = readVin();
		gVin = Vin;

		double Vout = readVout();

		double Iout = readIOut();

		//update display only when enough time has passed or a setting has been changed
		uint32_t timeFlag = __HAL_TIM_GET_COUNTER(&htim11) - timerVal;
		if ((timeFlag >= REFRESH_INTERVAL) || swIntFlag == SET)
		{
			displayVoltageCurrent(Vin, Vout, Iout);
			if (timeFlag >= REFRESH_INTERVAL)
				timerVal = __HAL_TIM_GET_COUNTER(&htim11);
		}

		//only handle buttons if interrupt was flagged
		if (swIntFlag == SET)
		{
			buttonsHandler(whichBtn());
			swIntFlag = RESET;
		}

		//check for current surpassing set limit
		if (Iout > psuStats.iSet)
		{
			psuStats.iLim = I_LIM_SET;
		}
		else
		{
			psuStats.iLim = I_LIM_NSET;
		}

		//set LEDs according to setup/errors
		setLeds(psuStats);
    /* USER CODE END WHILE */

    /* USER CODE BEGIN 3 */
	}
  /* USER CODE END 3 */
}

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
/* USER CODE BEGIN 4 */
void initPSU(void)
{
	initLeds();
	//init struct for PSU
	psuStats.vSet = V_DEFAULT;
	psuStats.iSet = I_DEFAULT;
	psuStats.iLim = I_LIM_DEFAULT;
	psuStats.VI = VI_DEFAULT;
	psuStats.OE = OE_DEFAULT;

	//show current settings on LEDs
	setLeds(psuStats);

	//init and show logo on OLED
	ssd1306_Init();
	ssd1306_Fill(SSD1306_BLACK);
	showStartup();
	HAL_StatusTypeDef adcRet = HAL_ADC_Start(&hadc1);
	if (adcRet != HAL_OK)
	{
		ssd1306_WriteErrorMsg(2, 12, "ADC start failed");
	}

	//set pot value for Vout (half)
	MCP4018_WriteVal(psuStats.vSet);

	//initialize screen update timer
	HAL_TIM_Base_Start(&htim11);
	timerVal = __HAL_TIM_GET_COUNTER(&htim11);
}

void showStartup(void)
{
	//show logo
	ssd1306_DrawBitMap(0, 0, BOOTSCREEN, 128, 32, SSD1306_WHITE);
	osDelay(2000);
}

void displayVin(double Vin)
{
	char buff[10] =
	{ };

	//Display voltage in
	ssd1306_SetCursor(INFO_X, VIN_Y);
	ssd1306_WriteString("Vin = ", INFO_TEXT_SIZE, SSD1306_WHITE);
	if (Vin > 1000)
	{
		sprintf(buff, "%4.2f", Vin / 1000);
		ssd1306_WriteString(buff, INFO_TEXT_SIZE, SSD1306_WHITE);
		ssd1306_WriteString("V", INFO_TEXT_SIZE, SSD1306_WHITE);
	}
	else
	{
		sprintf(buff, "%4.2f", Vin);
		ssd1306_WriteString(buff, INFO_TEXT_SIZE, SSD1306_WHITE);
		ssd1306_WriteString("mV", INFO_TEXT_SIZE, SSD1306_WHITE);
	}
}

void displayOnOff(void)
{
	//display whether PSU output is enabled
	ssd1306_SetCursor(ON_OFF_X, VIN_Y);
	if (psuStats.OE == OE_ENABLED)
		ssd1306_WriteString("ON   ", INFO_TEXT_SIZE, SSD1306_WHITE);
	else
		ssd1306_WriteString("OFF", INFO_TEXT_SIZE, SSD1306_WHITE);

}

void displaySetVoltage(void)
{
	char buff[10] =
	{ };
	//display set voltage
	ssd1306_SetCursor(INFO_X, VSET_Y);
	ssd1306_WriteString("Vset = ", INFO_TEXT_SIZE, SSD1306_WHITE);
	if (vSetCalc() >= 1000)
	{
		sprintf(buff, "%4.2f", (double) vSetCalc() / 1000.0);
		ssd1306_WriteString(buff, INFO_TEXT_SIZE, SSD1306_WHITE);
		if (psuStats.VI == VI_V_SEL)
			ssd1306_WriteString("V <<", INFO_TEXT_SIZE, SSD1306_WHITE);
		else
			ssd1306_WriteString("V     ", INFO_TEXT_SIZE, SSD1306_WHITE);
	}
	else
	{
		sprintf(buff, "%4.2f", (double) vSetCalc());
		ssd1306_WriteString(buff, INFO_TEXT_SIZE, SSD1306_WHITE);
		if (psuStats.VI == VI_V_SEL)
			ssd1306_WriteString("mV <<", INFO_TEXT_SIZE, SSD1306_WHITE);
		else
			ssd1306_WriteString("mV     ", INFO_TEXT_SIZE, SSD1306_WHITE);
	}
}

void displayVout(double V)
{
	char buff[10] =
	{ };
	//display output voltage
	ssd1306_SetCursor(INFO_X, VOUT_Y);
	ssd1306_WriteString("Vout = ", INFO_TEXT_SIZE, SSD1306_WHITE);
	if (V >= 1000)
	{
		sprintf(buff, "%4.2f", V / 1000.0);
		ssd1306_WriteString(buff, INFO_TEXT_SIZE, SSD1306_WHITE);
		ssd1306_WriteString("V", INFO_TEXT_SIZE, SSD1306_WHITE);
	}
	else
	{
		sprintf(buff, "%4.2f", V);
		ssd1306_WriteString(buff, INFO_TEXT_SIZE, SSD1306_WHITE);
		ssd1306_WriteString("mV", INFO_TEXT_SIZE, SSD1306_WHITE);
	}

}

void displaySetCurrent(void)
{
	char buff[10] =
	{ };
	//display set current
	ssd1306_SetCursor(INFO_X, ISET_Y);
	ssd1306_WriteString("Iset = ", INFO_TEXT_SIZE, SSD1306_WHITE);
	if (psuStats.iSet >= 1000)
	{
		sprintf(buff, "%4.2f", (double) psuStats.iSet / 1000.0);
		ssd1306_WriteString(buff, INFO_TEXT_SIZE, SSD1306_WHITE);
		if (psuStats.VI == VI_I_SEL)
			ssd1306_WriteString("A <<", INFO_TEXT_SIZE, SSD1306_WHITE);
		else
			ssd1306_WriteString("A     ", INFO_TEXT_SIZE, SSD1306_WHITE);
	}
	else
	{
		sprintf(buff, "%4.2f", (double) psuStats.iSet);
		ssd1306_WriteString(buff, INFO_TEXT_SIZE, SSD1306_WHITE);
		if (psuStats.VI == VI_I_SEL)
			ssd1306_WriteString("mA <<", INFO_TEXT_SIZE, SSD1306_WHITE);
		else
			ssd1306_WriteString("mA     ", INFO_TEXT_SIZE, SSD1306_WHITE);
	}
}

void displayIout(double I)
{
	char buff[10] =
	{ };
	//display output current
	ssd1306_SetCursor(INFO_X, IOUT_Y);
	ssd1306_WriteString("Iout = ", INFO_TEXT_SIZE, SSD1306_WHITE);
	if (I >= 1000)
	{
		sprintf(buff, "%4.2f", I / 1000.0);
		ssd1306_WriteString(buff, INFO_TEXT_SIZE, SSD1306_WHITE);
		ssd1306_WriteString("A", INFO_TEXT_SIZE, SSD1306_WHITE);
	}
	else
	{
		sprintf(buff, "%4.2f", I);
		ssd1306_WriteString(buff, INFO_TEXT_SIZE, SSD1306_WHITE);
		ssd1306_WriteString("mA", INFO_TEXT_SIZE, SSD1306_WHITE);
	}
}

void displayVoltageCurrent(double Vin, double V, double I)
{
	//clear screen
	ssd1306_Fill(SSD1306_BLACK);

	displayVin(Vin);

	displayOnOff();

	displaySetVoltage();

	displayVout(V);

	displaySetCurrent();

	displayIout(I);

	ssd1306_UpdateScreen();
}

void enableOutput(void)
{
	HAL_GPIO_WritePin(REG_EN_GPIO_Port, REG_EN_Pin, GPIO_PIN_RESET);
}

void disableOutput(void)
{
	HAL_GPIO_WritePin(REG_EN_GPIO_Port, REG_EN_Pin, GPIO_PIN_SET);
}

void buttonsHandler(uint8_t buttons)
{
	printBtns(buttons);
	if (buttons & BTN_NUM_VI)
	{
		if (psuStats.VI == VI_V_SEL)
		{
			psuStats.VI = VI_I_SEL;
		}
		else if (psuStats.VI == VI_I_SEL)
		{
			psuStats.VI = VI_V_SEL;
		}
		else
		{ //something went wrong, reinit psu
			fatalErrorScreen();
			initPSU();
		}

	}

	if (buttons & BTN_NUM_UP)
	{
		if (psuStats.VI == VI_V_SEL)
		{
			psuStats.vSet--;	//reduce R to increase V
			MCP4018_WriteVal(psuStats.vSet);
		}
		else if (psuStats.VI == VI_I_SEL)
		{
			psuStats.iSet += 50;
		}
		else
		{ //something went wrong, reinit psu
			fatalErrorScreen();
			initPSU();
		}
	}

	if (buttons & BTN_NUM_DWN)
	{
		if (psuStats.VI == VI_V_SEL)
		{
			psuStats.vSet++;	//increase R to decrease V
			MCP4018_WriteVal(psuStats.vSet);
		}
		else if (psuStats.VI == VI_I_SEL)
		{
			psuStats.iSet -= 50;
		}
		else
		{ //something went wrong, reinit psu
			fatalErrorScreen();
			initPSU();
		}
	}

	if (buttons & BTN_NUM_OE)
	{
		if (psuStats.OE == OE_ENABLED)
		{
			psuStats.OE = OE_DISABLED;
			disableOutput();
		}
		else if (psuStats.OE == OE_DISABLED)
		{
			psuStats.OE = OE_ENABLED;
			enableOutput();
		}
		else
		{ //something went wrong, reinit psu
			fatalErrorScreen();
			initPSU();
		}
	}
	displayOnOff();
	displaySetVoltage();
	displaySetCurrent();
	ssd1306_UpdateScreen();

}

uint32_t vSetCalc(void)
{
	double potCalc = (((double)psuStats.vSet / 128.0)) * 5000.0;
	double temp = 800.0 * ((4690.0 / potCalc) + 1.0);
	return (uint32_t)(temp);
}

void fatalErrorScreen(void)
{
	disableOutput();
	//clear screen
	ssd1306_Fill(SSD1306_BLACK);

	ssd1306_SetCursor(2, 0);
	ssd1306_WriteString("FATAL", ERROR_TEXT_SIZE, SSD1306_WHITE);
	ssd1306_SetCursor(2, 20);
	ssd1306_WriteString("ERROR!", ERROR_TEXT_SIZE, SSD1306_WHITE);

	//countdown 5 seconds
	ssd1306_SetCursor(2, 40);
	ssd1306_WriteString("Reinit(5)!", INFO_TEXT_SIZE, SSD1306_WHITE);
	ssd1306_UpdateScreen();
	osDelay(1000);

	ssd1306_SetCursor(2, 40);
	ssd1306_WriteString("Reinit(4)!.", INFO_TEXT_SIZE, SSD1306_WHITE);
	ssd1306_UpdateScreen();
	osDelay(1000);

	ssd1306_SetCursor(2, 40);
	ssd1306_WriteString("Reinit(3)!..", INFO_TEXT_SIZE, SSD1306_WHITE);
	ssd1306_UpdateScreen();
	osDelay(1000);

	ssd1306_SetCursor(2, 40);
	ssd1306_WriteString("Reinit(2)!...", INFO_TEXT_SIZE, SSD1306_WHITE);
	ssd1306_UpdateScreen();
	osDelay(1000);

	ssd1306_SetCursor(2, 40);
	ssd1306_WriteString("Reinit(1)!....", INFO_TEXT_SIZE, SSD1306_WHITE);
	ssd1306_UpdateScreen();
	osDelay(1000);

	ssd1306_SetCursor(2, 40);
	ssd1306_WriteString("Reinit(0)!.....", INFO_TEXT_SIZE, SSD1306_WHITE);
	ssd1306_UpdateScreen();
	osDelay(1000);

	//flash screen
	ssd1306_Fill(SSD1306_WHITE);
	ssd1306_UpdateScreen();
	osDelay(50);
	ssd1306_Fill(SSD1306_BLACK);
	ssd1306_UpdateScreen();
	osDelay(50);
	ssd1306_Fill(SSD1306_WHITE);
	ssd1306_UpdateScreen();
	osDelay(50);
	ssd1306_Fill(SSD1306_BLACK);
	ssd1306_UpdateScreen();
	osDelay(50);
	ssd1306_Fill(SSD1306_WHITE);
	ssd1306_UpdateScreen();
	osDelay(50);
}

void printSettings(void)
{
//	  struct Stats
//	  {
//	    uint8_t vSet;  //voltage set in a byte for MCP4018
//	    uint32_t iSet; //current set in mA
//	    uint8_t iLim;  //bit[0] ? limit reached : limit NOT reached
//	    uint8_t OE;    //bit[0] ? enabled : disabled
//	    uint8_t VI;    //bit[0] ? voltage : current
//	  };
	printMsg("\nSet Voltage = %dmV\n", vSetCalc());
	printMsg("Set Current = %dmA\n", psuStats.iSet);
	printMsg("Current Limit Reached: %s\n",
			(psuStats.iLim == I_LIM_NSET) ? "FALSE" : "TRUE");
	printMsg("Output: %s\n", (psuStats.OE == OE_ENABLED) ? "TRUE" : "FALSE");
	printMsg("V/I Sel: %s\n\n",
			(psuStats.VI == VI_V_SEL) ? "Voltage" : "Current");
}

void HAL_GPIO_EXTI_Callback(uint16_t GPIO_Pin)
{
	if (GPIO_Pin == nSW_INT_Pin) // If The INT Source Is EXTI Line9 (A9 Pin)
	{
		swIntFlag = SET;
	}
}

/* USER CODE END 4 */
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


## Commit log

2020-08-02 Schematic almost complete
    Add relay, display, connectors, mounting
    [Power_Supply.kicad_pcb, Power_Supply.kicad_sch]
2020-08-03 staring layout... need to add input connection
    [Power_Supply.kicad_pcb, Power_Supply.kicad_sch]
2020-08-03 need to add display
    [Power_Supply.kicad_pcb]
2020-08-03 schematic general changes
    [Power_Supply.kicad_sch]
2020-08-08 layout complete - OLED missing
    [Power_Supply.kicad_pcb, Power_Supply.kicad_sch]
2020-08-08 schem - added bypass caps
    [Power_Supply.kicad_sch]
2020-08-08 added 3-d models for binding posts and relays
    [Power_Supply.kicad_pcb, Relay ALQ305 v5.step]
2020-08-08 did via stitching for ground
    [Power_Supply.kicad_pcb, Power_Supply.kicad_sch]
2020-08-08 layout complete - need to clean scehmatic, add logo, generate gerber/BOM
    [Power_Supply.kicad_pcb]
2020-08-09 removed relay - control EN with regulator pin
    [0.91_ OLED v12.step, Power_Supply copy.kicad_pcb, Power_Supply.kicad_pcb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]
2020-08-10 working on 3-d model
    [Power_Supply-B_Cu.gbr, Power_Supply-B_Mask.gbr, Power_Supply-B_Paste.gbr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]
2020-08-13 init new version with esp32
    [0.91_ OLED v12.step, Power_Supply copy.kicad_pcb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]
2020-08-14 added esp32 to schematic
    [ESP32-S2-WROVER.STEP, Power_Supply.kicad_pcb, Power_Supply.kicad_sch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]
2020-08-24 placed all components
    [Power_Supply V1.kicad_pcb, Power_Supply copy.kicad_pcb, Power_Supply.kicad_pcb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]
2020-08-24 schematic update-removed unnecessary resistors
    [Power_Supply.kicad_sch]
2020-08-25 finished layout for PCB with USB
    [Power_Supply.kicad_pcb, Power_Supply.kicad_sch]
2020-08-25 reorganized HW folder
    [0.91_ OLED v12.step, Power_Supply V1.kicad_pcb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]
2020-08-25 changed MCU to atmega328p for easier arduino dev
    [Power_Supply.kicad_pcb, Power_Supply.kicad_sch]
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2020-08-27 subbed 0.91in with 0.96 OLED
    [Power_Supply.kicad_pcb, Power_Supply.kicad_sch]
2020-08-27 removed PCB copy
    [0.91_ OLED v12.step, ESP32-S2-WROVER.STEP, Power_Supply copy.kicad_pcb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]
2020-08-27 added current limiting resistors on transistors
    [Power_Supply.kicad_pcb, Power_Supply.kicad_sch]
2020-08-27 added gerber files, 3-d model and schematic PDF
    [Power_Supply-B_Cu.gbr, Power_Supply-B_Mask.gbr, Power_Supply-B_Paste.gbr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]
2020-08-28 Added Vin measurement
    [Power_Supply-B_Cu.gbr, Power_Supply-B_Mask.gbr, Power_Supply-B_Paste.gbr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]
2020-08-28 updated silkscreen
    [0.91_ OLED v12.step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]
2020-08-29 added high voltage digi_pot control
    [Power_Supply.kicad_pcb, Power_Supply.kicad_sch]
2020-08-29 updated hardware output files
    [Power_Supply-B_Cu.gbr, Power_Supply-B_Mask.gbr, Power_Supply-B_Paste.gbr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]
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2020-09-04 ac-dc converter init
    [0.91_ OLED v12.step, BOM.csv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]
2020-09-04 ac dc converter schem complete
    [Power_Supply.kicad_pcb]
2020-09-04 changed input connector
    [Power_Supply.kicad_sch]
2020-09-05 ac-dc layout compelte
    [Power_Supply.kicad_pcb]
2020-09-05 ac-dc layout complete and added 3d models
    [Power_Supply.kicad_pcb, Power_Supply.kicad_sch]
2020-09-07 gerber files updated
    [0.91_ OLED v12.step, 0.91_ OLED.step, AC_PCB.stp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]
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2020-09-18 fixed buffer errors
    [Power_Supply.kicad_pcb, Power_Supply.kicad_sch]
2020-09-18 updated gerbers
    [Power_Supply-B_Cu.gbr, Power_Supply-B_Mask.gbr, Power_Supply-B_Paste.gbr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]
2020-09-27 exported production files
    [Panelized_Power_Supply-B_Cu.gbr, Panelized_Power_Supply-B_Mask.gbr, Panelized_Power_Supply-B_Paste.gbr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]
2020-09-27 v2 init
    [0.91_ OLED v12.step, 0.91_ OLED.step, AC_PCB.stp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]
2020-09-27 removed unnecessary files
    [Panelized_Power_Supply.kicad_pcb]
2020-10-01 esp32 init
    [Power_Supply.kicad_sch]
2020-10-18 altium init
    [MCU.SchDoc, PSU.PrjPcb, USB.SchDoc]
2020-10-18 added USB schem
    [USB.SchDoc]
2020-11-05 v2 pcb init
    [MCU.SchDoc, PSU.PrjPcb]
2020-11-06 schem init
    [MCU.SchDoc, PSU.PrjPcb, USB.SchDoc]
2020-11-12 mcu labels comeplte
    [MCU.SchDoc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]
2020-11-15 pin planning
    [MCU.SchDoc]
2020-11-16 started power
    [MCU.SchDoc, PSU.PrjPcb, Power.SchDoc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]
2020-11-16 project update
    [PSU.PrjPcb]
2020-11-19 lcd added
    [MCU.SchDoc, PSU.PrjPcb, Power.SchDoc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]
2020-11-19 added pot and amps
    [MCU.SchDoc, Power.SchDoc, UI.SchDoc]
2020-11-20 added v and I sense
    [MCU.SchDoc, Power.SchDoc]
2020-11-20 addign peripherals
    [MCU.SchDoc, Power.SchDoc, UI.SchDoc]
2020-11-21 added uart - usb
    [UI.SchDoc]
2020-11-21 project updates
    [UI.SchDoc]
2020-11-21 PCB PLANNING
    [MCU.SchDoc, PCB.PcbDoc, PSU.PrjPcb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]
2020-11-21 planning complete
    [PCB.PcbDoc]
2020-11-23 starting routing
    [PCB.PcbDoc, PSU.PrjPcb, UI.SchDoc]
2020-11-23 need to fix oled footprint
    [PCB.PcbDoc]
2020-11-23 ground routing
    [MCU.SchDoc, PCB.PcbDoc, Power.SchDoc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]
2020-11-24 continuing power routing
    [PCB.PcbDoc, UI.SchDoc]
2020-11-26 routing complete
    [PCB.PcbDoc]
2020-12-15 rollback FW
    [Panelized_Power_Supply.kicad_pcb]
2020-12-15 fixed buttons and wiperlock function
    [buttons.cpp, main.cpp]
2020-12-15 fixed enable led
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2020-12-30 added usb power pass thru
    [PCB.GBL, PCB.GBO, PCB.GBP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]
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2021-01-03 fixed usb voltage stuff and generated outputs
    [PCB.PcbDoc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]
2021-01-04 fix mic enable pin
    [MCU.SchDoc, PCB.PcbDoc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]
2021-01-04 fixed mic enable with external power
    [main.cpp]
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2021-01-08 Spaced out passives for easier hand soldering
    [MCU.SchDoc, PCB_V3.PcbDoc, PSU.PrjPcb]
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2021-01-25 fixed buffer power rails
    [PCB_V3.PcbDoc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]
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2021-01-30 replaced stdc connector (swd) and fixed silk
    [MCU.SchDoc, PCB.PcbDoc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]
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2021-02-15 Changed uC to f410 and fixed buttons/UART/I2C
    [PSW_FW_F410RB.ioc, analog.c, analog.h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]
2021-02-16 fixed display delayed update
    [main.c, main.h]
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2021-02-16 Need to fix vset calc line 735 - main
    [PSW_FW_F410RB.ioc, analog.c, main.c]
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2021-03-10 UART TX changed to use DMA
    [PSU.kicad_pcb, PSU.kicad_sch]
2021-03-10 uart tx format specifiers not working
    [main.c, uart.c]
2021-03-11 DMA tx w format specifiers fixed - needed larger stack for thread
    [main.c, uart.c]
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2021-03-17 btns fixed. need to add mcp4018 control
    [main.c, main.h]
2021-03-21 fixed switching diode, bulk cap and added non-volatile flash
    [0.91_ OLED v12.step, AC_PCB.stp, BOM.csv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]
2021-04-13 fixed current measurements
2021-04-13 fixed current limit led
    [analog.c, main.c]
2022-02-28 Removed unnecessary projects and files
    [PCB_V1.PcbDoc, PCB_V2.PcbDoc]
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2022-03-11 Project cleanup with init of V3
    [0.91_ OLED.step, MCU.SchDoc, PCB_V3.PcbDoc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]

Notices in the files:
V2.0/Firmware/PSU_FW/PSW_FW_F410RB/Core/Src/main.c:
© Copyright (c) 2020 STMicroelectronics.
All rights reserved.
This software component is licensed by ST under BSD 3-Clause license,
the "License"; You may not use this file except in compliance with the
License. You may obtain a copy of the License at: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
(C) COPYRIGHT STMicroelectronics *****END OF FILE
